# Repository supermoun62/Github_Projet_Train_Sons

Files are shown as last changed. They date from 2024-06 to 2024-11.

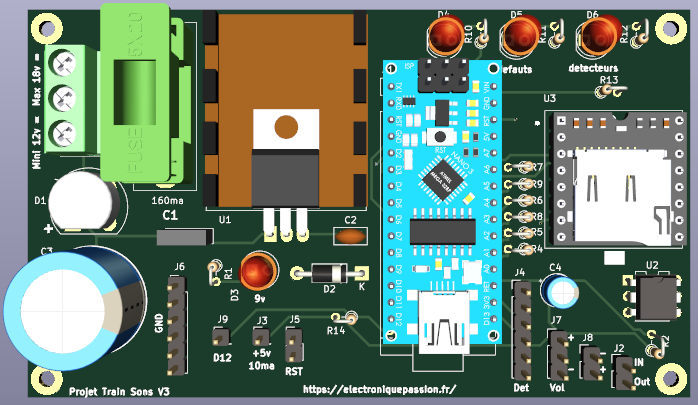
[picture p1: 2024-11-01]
PCB_Implantation_Projet_Trains_Sons.png

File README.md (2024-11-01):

Gestion de sons sur une maquette de trains.

Programmes Arduino:V1,V2,V3,V4,V5,V6

Materiel_Projet_Trains_Sons.pdf

Schema_Projet_Train_Sons.pdf
Schema_Nano.pdf

Documentations_Projet_Trains_Sons.pdf

Kicad_Gerber_Projet_Train_Sons

Kicad_PDF_Projet_Train_Sons

Le fichier Kicad_PDF_Projet_Train_Sons.pdf contient le détail du projet.

Schéma Projet_Trains_Sons: https://github.com/supermoun62/Github_Projet_Train_Sons/blob/main/Schema_Projet_Trains_Sons_V3.pdf

PCB Projet_Trains_Sons: https://github.com/supermoun62/Github_Projet_Train_Sons/blob/main/PCB_Implantation_Projet_Trains_Sons.png

Tracé Projet_Trains_Sons: https://github.com/supermoun62/Github_Projet_Train_Sons/blob/main/PCB_Projet_Trains_Sons_V3.png

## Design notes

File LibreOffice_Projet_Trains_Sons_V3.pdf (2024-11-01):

# PROJET

Commande de sons sur une maquette de trains.

Train-Sons | http://electroniquepassion.fr | 1 Sur 22

## Arduino - Trains - Sons

Le dossier comprend:

Programme Arduino.

Schéma de câblage.

Diverses documentations.

Liste du matériel.

Dossier Kicad en Gerber et PDF.

Train-Sons | http://electroniquepassion.fr | 2 Sur 22

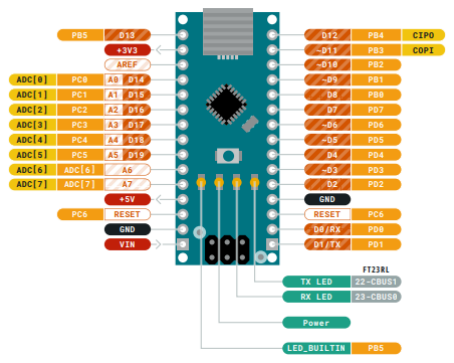
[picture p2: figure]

A4 = SDA
A5 = SCL

https://docs.arduino.cc/resources/pinouts/A000005-full-pinout.pdf

Train-Sons | http://electroniquepassion.fr | 3 Sur 22

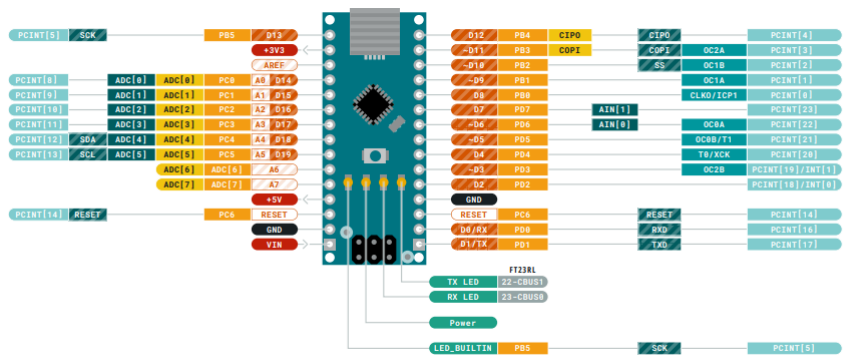
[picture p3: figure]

Train-Sons | http://electroniquepassion.fr | 4 Sur 22

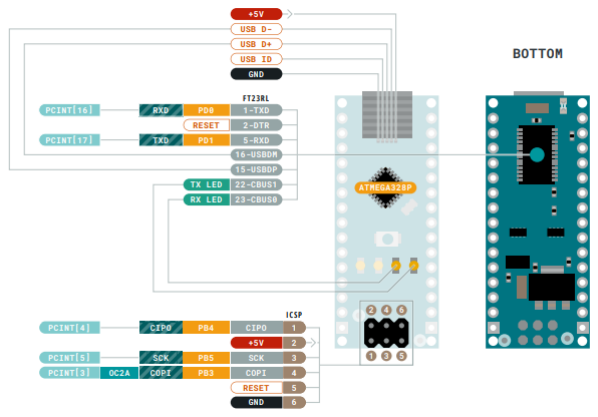
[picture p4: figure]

Train-Sons | http://electroniquepassion.fr | 5 Sur 22

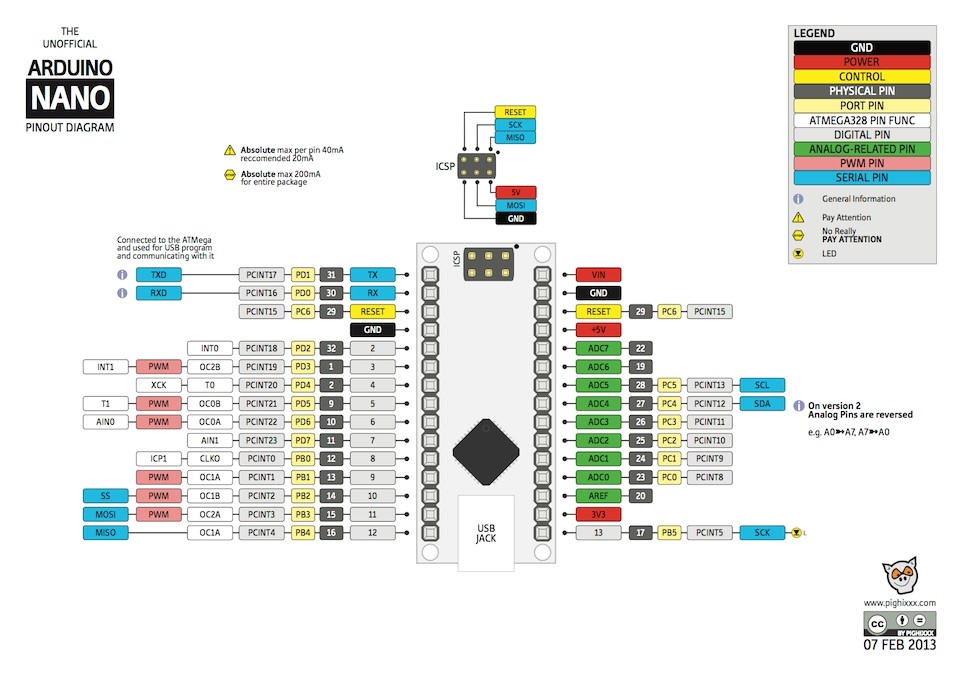
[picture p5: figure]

Train-Sons | http://electroniquepassion.fr | 6 Sur 22

https://docs.arduino.cc/learn/built-in-libraries/software-serial/ Traduction Google

La bibliothèque SoftwareSerial permet la communication série sur d’autres broches numériques d’une carte Arduino, en utilisant un logiciel pour répliquer la fonctionnalité (d’où le nom « SoftwareSerial »). Il est possible d’avoir plusieurs ports série logiciels avec des vitesses allant jusqu’à 115200 bps. Un paramètre active la signalisation inversée pour les appareils qui nécessitent ce protocole.

La version de SoftwareSerial incluse dans la version 1.0 et les versions ultérieures est basée sur la bibliothèque NewSoftSerial de 'Mikal Hart'.
Pour utiliser cette bibliothèque:
#include <SoftwareSerial.h>

Limites de cette bibliothèque
La bibliothèque SoftwareSerial présente les limitations connues suivantes :

Il ne peut pas transmettre et recevoir des données en même temps.
Si vous utilisez plusieurs ports série logiciels, un seul peut recevoir des données à la fois.
Toutes les broches des cartes Mega et Mega 2560 ne prennent pas en charge les interruptions de modification, de sorte que seules les broches suivantes peuvent être utilisées pour RX : 10, 11, 12, 13, 14, 15, 50, 51, 52, 53, A8 (62), A9 (63), A10 (64), A11 (65), A12 (66), A13 (67), A14 (68), A15 (69). Toutes les broches des cartes Leonardo et Micro ne prennent pas en charge les interruptions de changement, de sorte que seuls les éléments suivants peuvent être utilisés pour RX : 8, 9, 10, 11, 14 (MISO), 15 (SCK), 16 (MOSI).
Sur les cartes Arduino ou Genuino 101, la vitesse RX maximale actuelle est de 57600bps.
Sur les cartes Arduino ou Genuino 101, RX ne fonctionne pas sur la broche numérique 13. Methods
SoftwareSerial()
Créez une instance d’un objet SoftwareSerial. Plusieurs objets SoftwareSerial peuvent être créés, mais un seul peut être actif à un moment donné.
Syntax
SoftwareSerial(rxPin, txPin, inverse_logic)
Parameters
rxPin: the pin on which to receive serial data.
txPin: the pin on which to transmit serial data.
inverse_logic : utilisé pour inverser le sens des bits entrants (la valeur par défaut est la logique normale). S’il est défini, SoftwareSerial traite un LOW (0v sur la broche, normalement) sur la broche RX comme un bit de 1 (l’état d’inactivité) et un HIGH (5V sur la broche, normalement) comme un bit de 0. Cela affecte également la façon dont il écrit sur la broche TX. La valeur par défaut est false.
Returns

None.

Train-Sons | http://electroniquepassion.fr | 7 Sur 22

## Haut Parleur : Max 3W

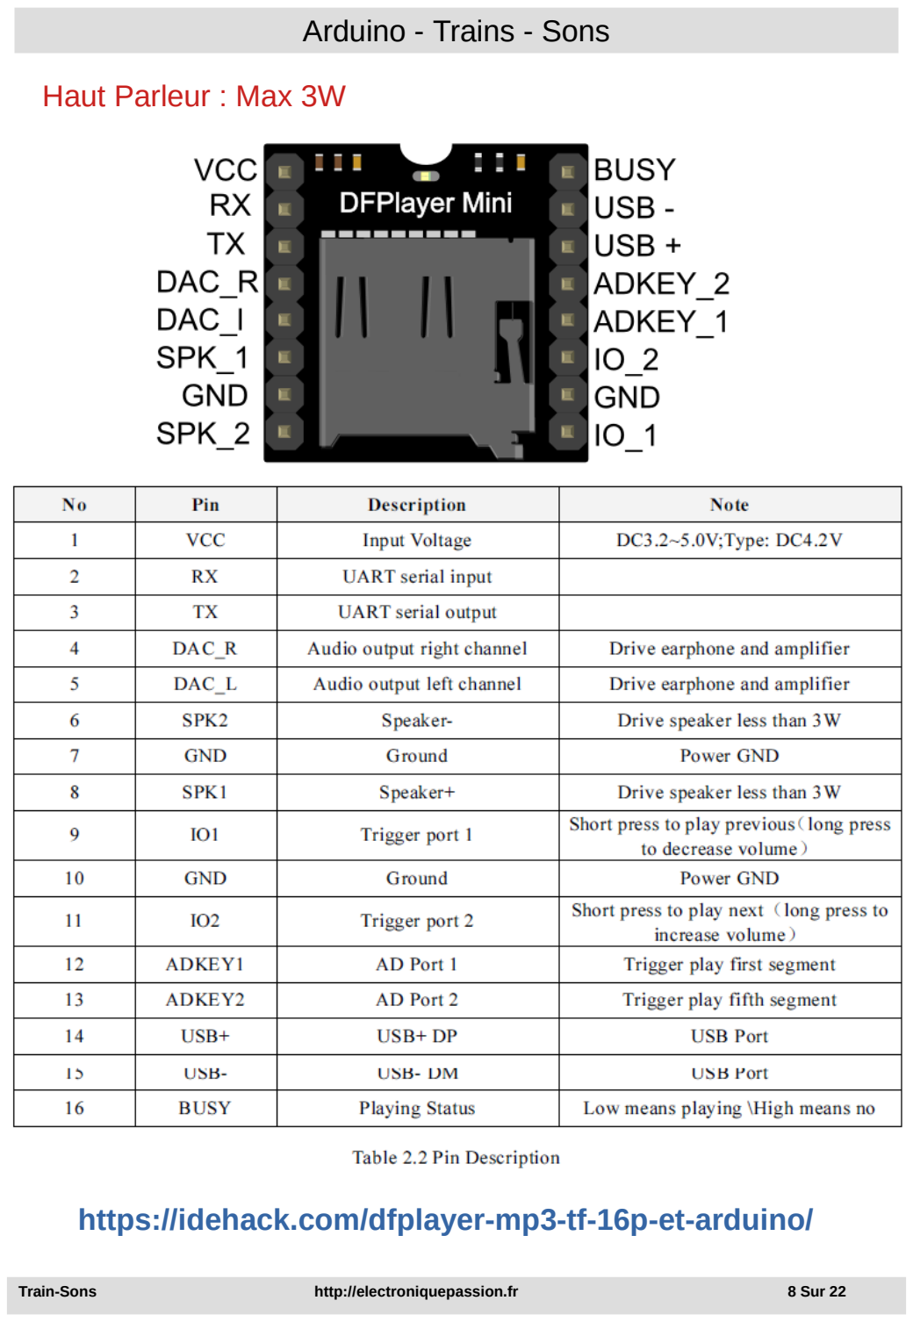
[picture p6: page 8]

https://wiki.dfrobot.com/DFPlayer_Mini_SKU_DFR0299

Train-Sons | http://electroniquepassion.fr | 8 Sur 22

## https://idehack.com/dfplayer-mp3-tf-16p-et-arduino/

Arduino_Train_Son_DFPlayer_Prog_Base.ino:

https://mytectutor.com/mp3-player-using-dfplayer-and-arduino/

https://github.com/DFRobot/DFPlayer-Mini-mp3?tab=readme-ov-file

https://github.com/DFRobot/DFRobot_utility

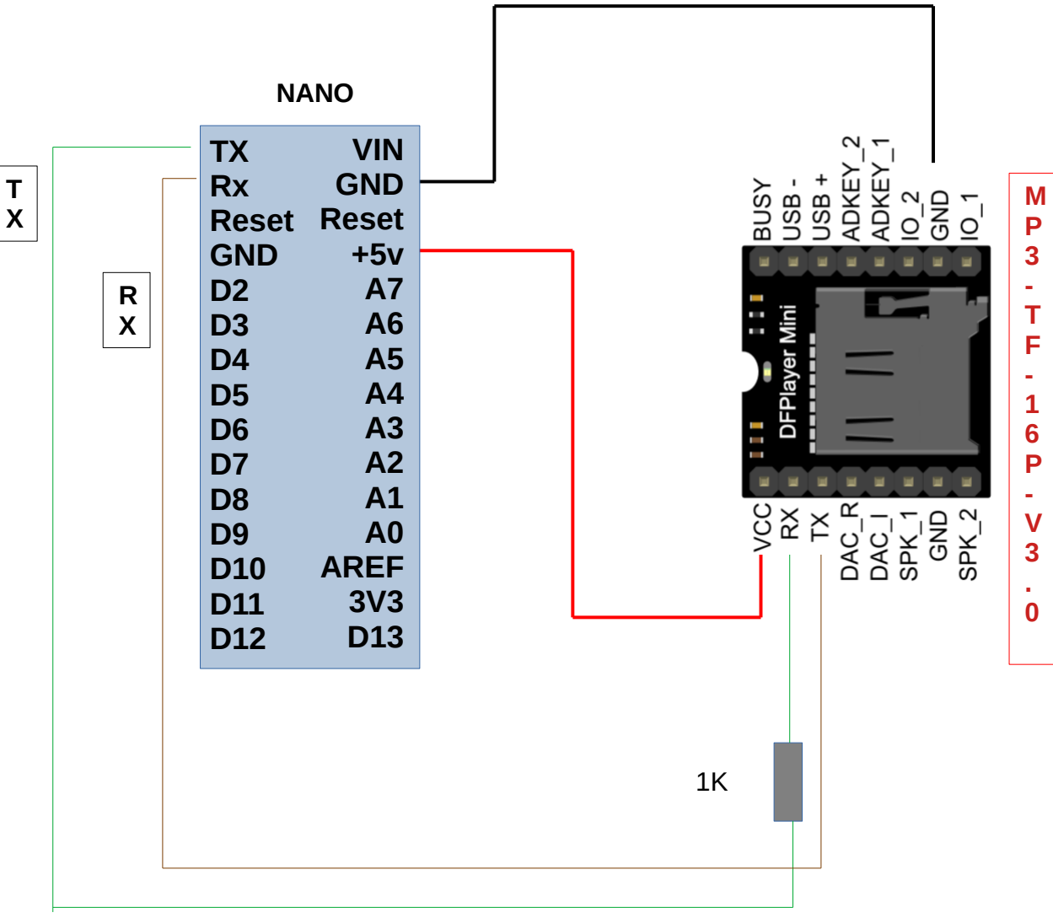
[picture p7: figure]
TX Rx Reset GND D2 D3 D4 D5 D6 D7 D8 D9 D10 D11 D12; NANO; VIN GND Reset +5v A7 A6 A5 A4 A3 A2 A1 A0 AREF 3V3 D13

En cas de transfert d’un programme, déconnecter les connexions TX et RX avant.

Train-Sons | http://electroniquepassion.fr | 9 Sur 22

Pour le programme de base :

Le contrôle simple du DFPlayer à l'aide d'Arduino, vous devrez installer la bibliothèque DFPlayer_Mini_Mp3.h et pour que cette bibliothèque fonctionne correctement, vous devrez également installer la bibliothèque DFRobot_utility.h.

Librairie DFRobotDFPlayerMini.h

https://github.com/DFRobot/DFRobotDFPlayerMini

Fonctions de base:

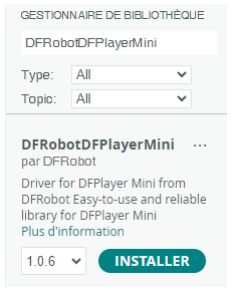
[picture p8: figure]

myDFPlayer.next(); | //Prochain fichier
myDFPlayer.previous(); | //Fichier précédent
myDFPlayer.play(1); | //Joue le premier fichier
myDFPlayer.loop(1); | //Joue le premier fichier en boucle
myDFPlayer.pause(); | //Mettre en pause la lecture
myDFPlayer.start(); | //reprendre la lecture du fichier en pause
myDFPlayer.playFolder(15, 4); //Joue le fichier 4 du dossier 15.
myDFPlayer.enableLoopAll(); | //Joue en boucle tous les fichiers.
myDFPlayer.disableLoopAll(); | //Arrête de lire en boucle tous les fichiers.
myDFPlayer.randomAll(); | //Joue tous les fichiers au hasard.
myDFPlayer.enableLoop(); | //Joue en boucle.
myDFPlayer.disableLoop(); | //Arrête la boucle.

Le nom du dossier allant de 1 à 99 et le nom du fichier de 1 à 255.

DFPlayer prend en charge les formats audio tels que MP3, WAV et WMA, qui peuvent être lus depuis une clé USB ou une carte SD.

REMARQUE: Le nom du dossier doit être mp3, placé sous le répertoire racine de la carte SD, et le nom du fichier mp3 doit être à 4 chiffres, par exemple, « 0001.mp3 », placé sous le dossier mp3. Si vous souhaitez le nommer à la fois en anglais et en chinois, vous pouvez l’ajouter après le numéro, par exemple, « 0001hello.mp3 » ou « 0001 后 » 来 .mp3".

Ou par le gestionnaire de
bibliothèque
Train-Sons | http://electroniquepassion.fr | 10 Sur 22

Arduino_Train_Son_DFPlayer_Prog_V1

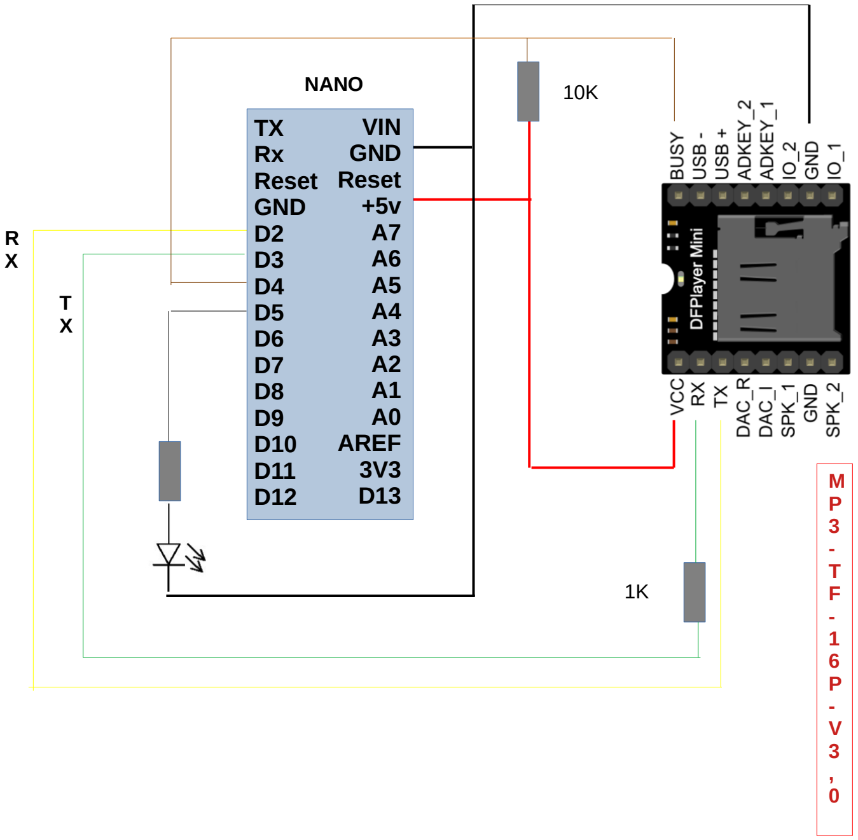
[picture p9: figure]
TX Rx Reset GND D2 D3 D4 D5 D6 D7 D8 D9 D10 D11 D12; NANO; VIN GND Reset +5v A7 A6 A5 A4 A3 A2 A1 A0 AREF 3V3 D13

Train-Sons | http://electroniquepassion.fr | 11 Sur 22

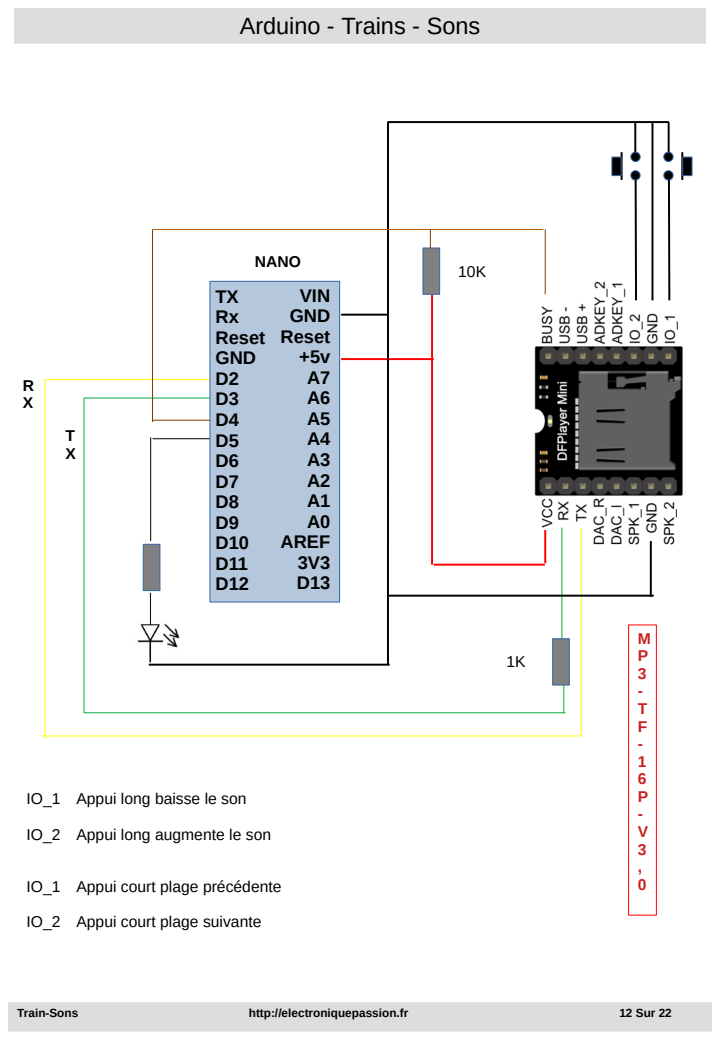
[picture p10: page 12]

IO_1 Appui long baisse le son

IO_2 Appui long augmente le son

IO_1 Appui court plage précédente

IO_2 Appui court plage suivante

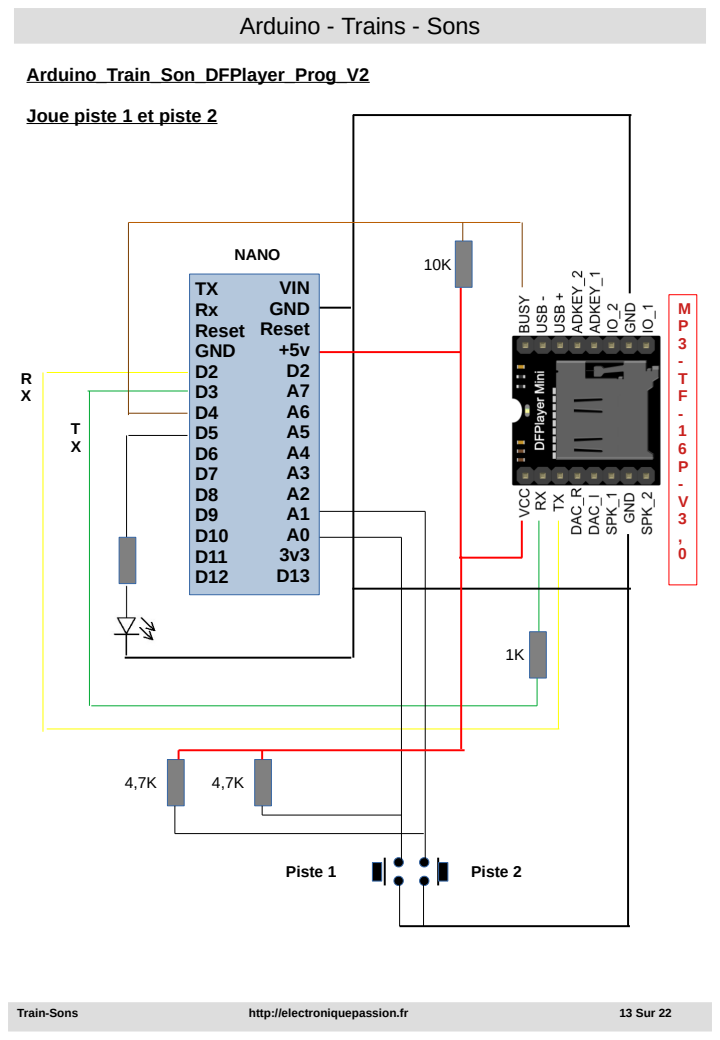
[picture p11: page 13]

Joue piste 1 et piste 2

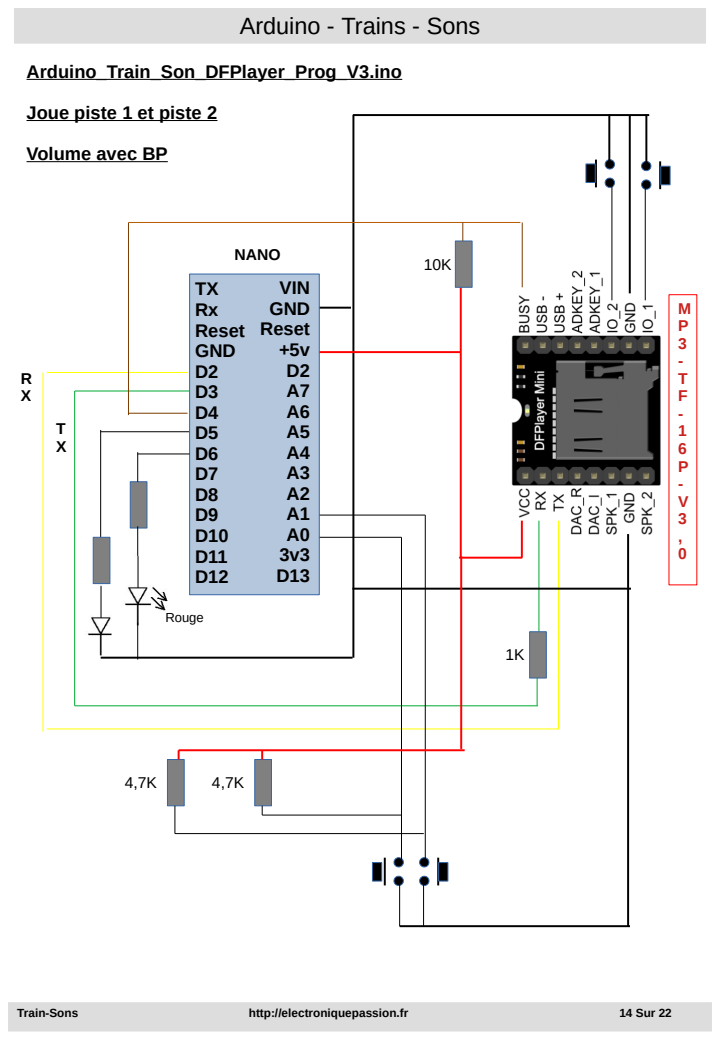
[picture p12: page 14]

Joue piste 1 et piste 2

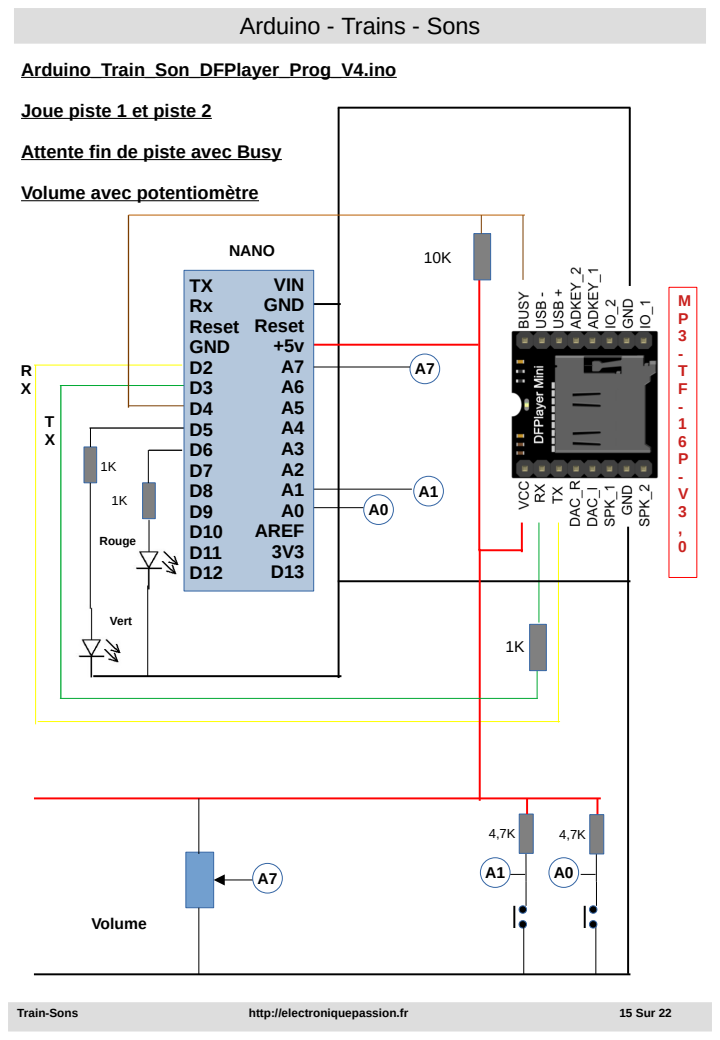
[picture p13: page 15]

Joue piste 1 et piste 2

Attente fin de piste avec Busy

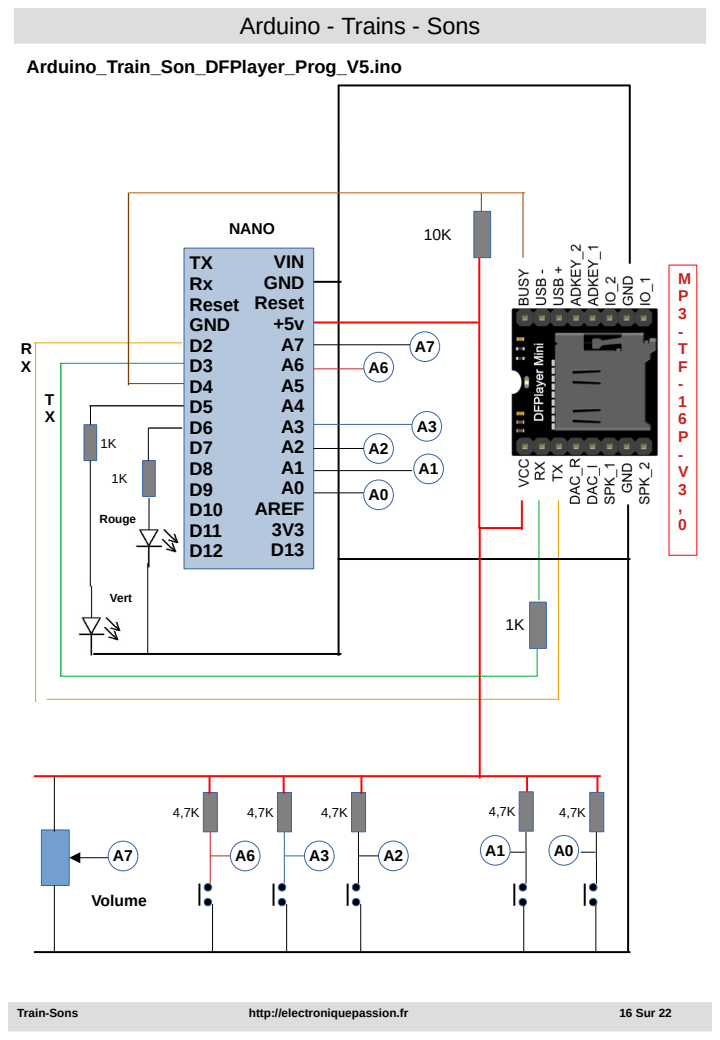
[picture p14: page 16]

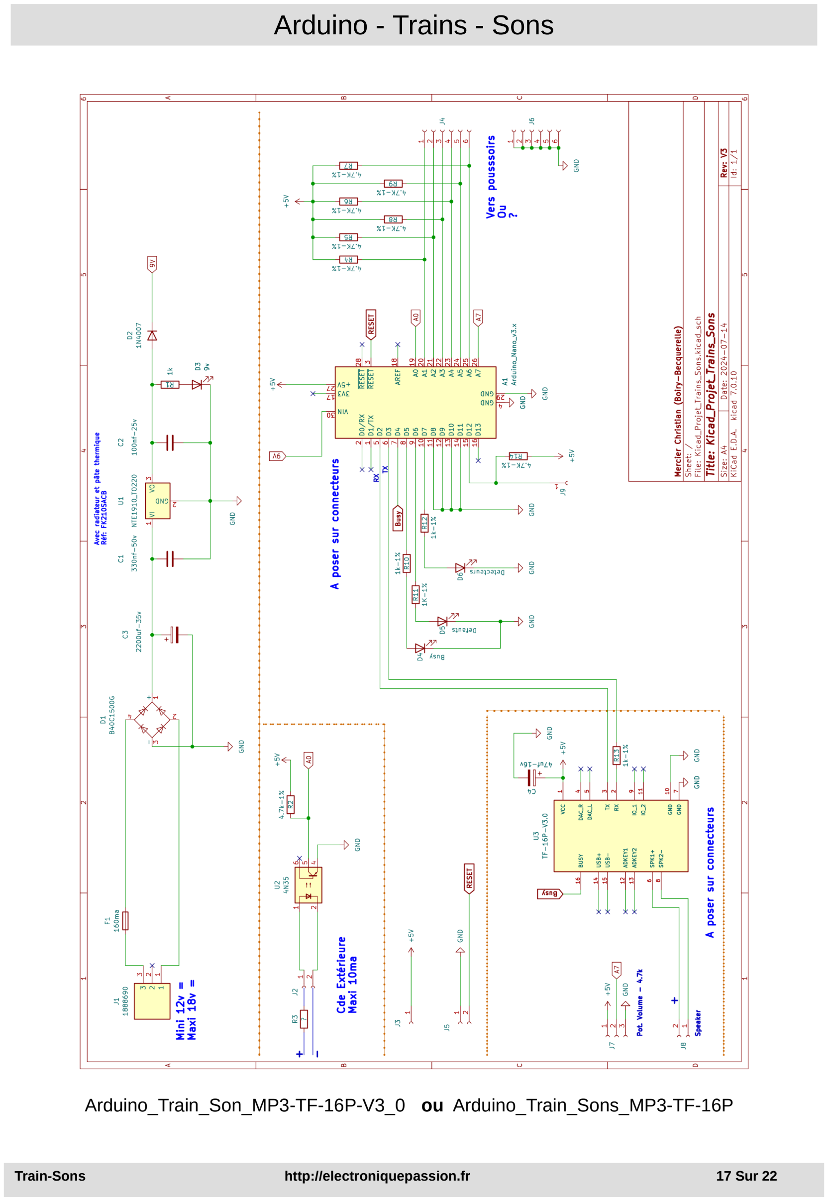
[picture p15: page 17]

Train-Sons | http://electroniquepassion.fr | 17 Sur 22

Arduino_Train_Son_MP3-TF-16P-V3_0 ou Arduino_Train_Sons_MP3-TF-16P

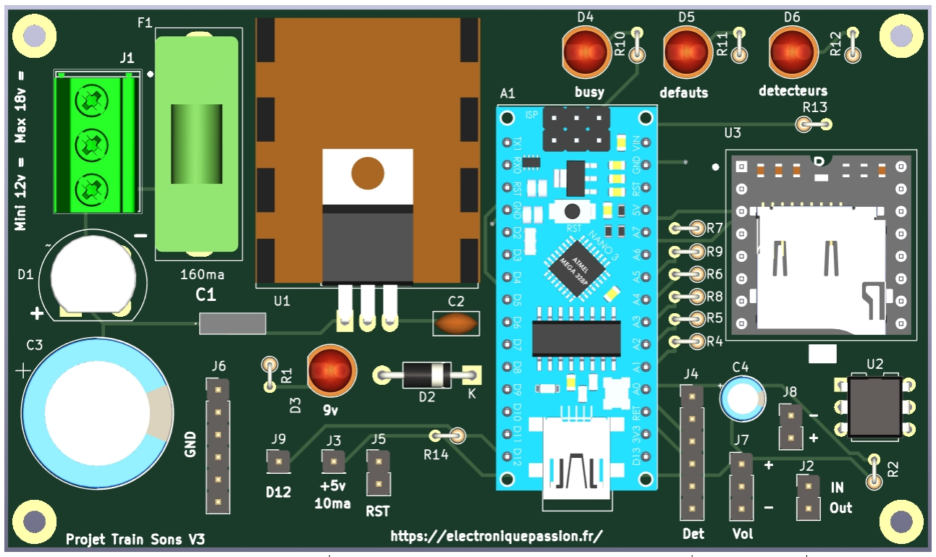
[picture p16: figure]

Train-Sons | http://electroniquepassion.fr | 18 Sur 22

0n peut relier J2 au connecteur J6 du projet Passage_A_niveau_Stockage_V4. Information sur le site:https://electroniquepassion.fr

Ne pas oublier la résistance R3 (voir image suivante)

GND

+5v
Maxi 10ma

Reset
Haut
parleur

Commande extérieure
avec isolation de potentiel. Courant à limiter à 10ma avec résistance(R3,sur le plan) Impulsion de 100ms

Entrée,Sortie
D12

Commandes

Train-Sons | http://electroniquepassion.fr | 19 Sur 22

Carte SD

## Les essais ont été effectués avec une carte formatée en

Fat 32.

Dossier intitulé mp3 à la racine.

## Fichiers sons nommés en 0001.mp3 0002.mp3 ------------- -------------

Carte passage à
niveau en stockage

Carte sons

+ 5v | D11 | OUT | IN

1k

J6 | J2

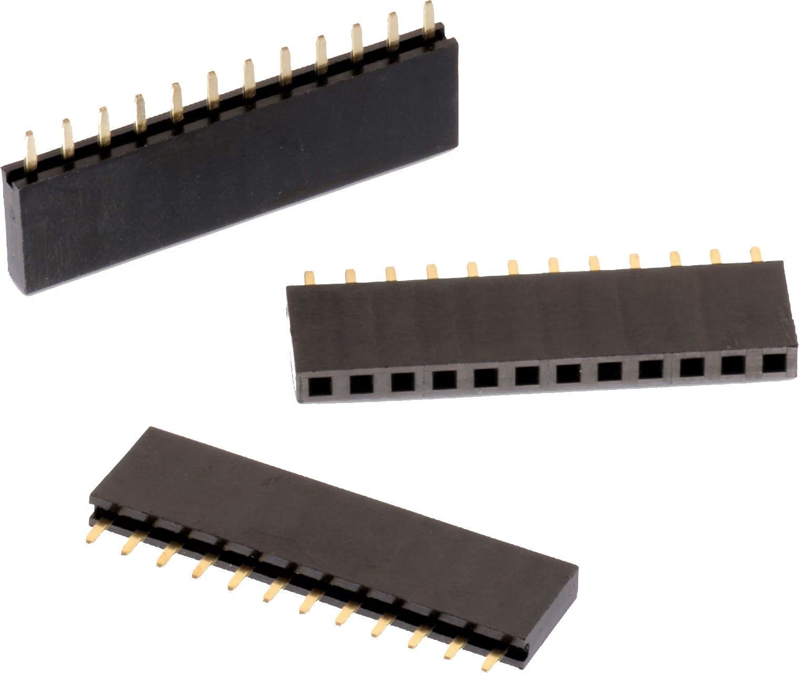
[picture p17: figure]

Train-Sons | http://electroniquepassion.fr | 20 Sur 22

https://www.we-online.com/en/components/products/PHD_2_54_SOCKET_HEADER_6130 XX11821 (https://www.we-online.com/en/components/products/PHD_2_54_SOCKET_HEADER_6130XX11821)

Train-Sons | http://electroniquepassion.fr | 21 Sur 22

Liens:

https://lasonotheque.org/search?q=train

https://idehack.com/dfplayer-mp3-tf-16p-et-arduino/

https://www.electronics-lab.com/project/mp3-player-using-arduino-dfplayer-mini/

https://www.wikidebrouillard.org/wiki/Item:DFPlayer_Lecteur_MP3

https://wiki.dfrobot.com/DFPlayer_Mini_SKU_DFR0299#Connection_Diagram

https://wiki.dfrobot.com/DFPlayer_Mini_SKU_DFR0299

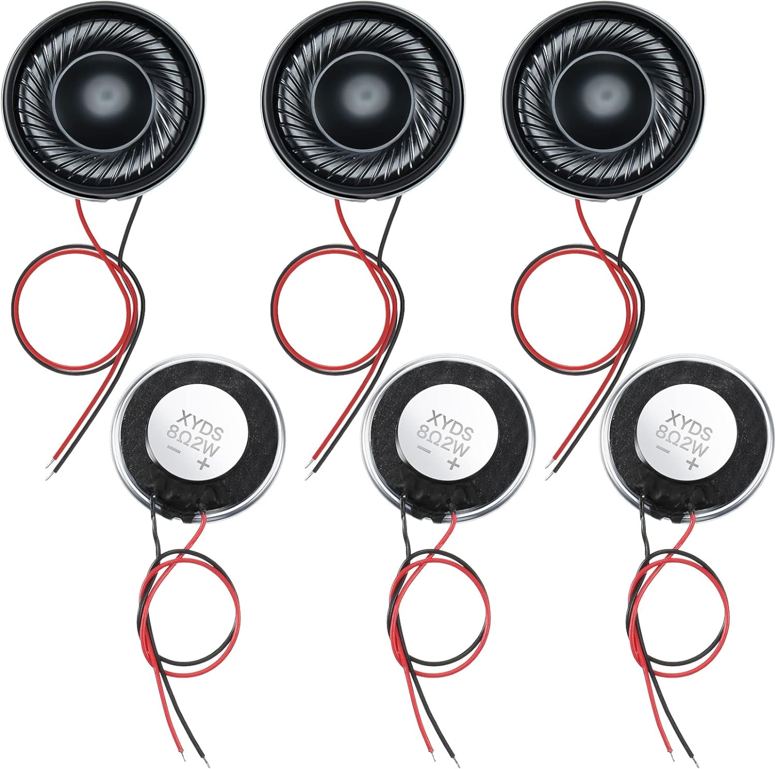
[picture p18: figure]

Weewooday Petits Haut-Parleurs 2 W 8 ohms Haut-Parleur à Aimant Interne Rond à Coque Métallique Micro Haut-Parleur Interne pour Mini Haut-Parleurs, DVD, EVD, Mini Haut-Parleurs Multimédia

Train-Sons | http://electroniquepassion.fr | 22 Sur 22

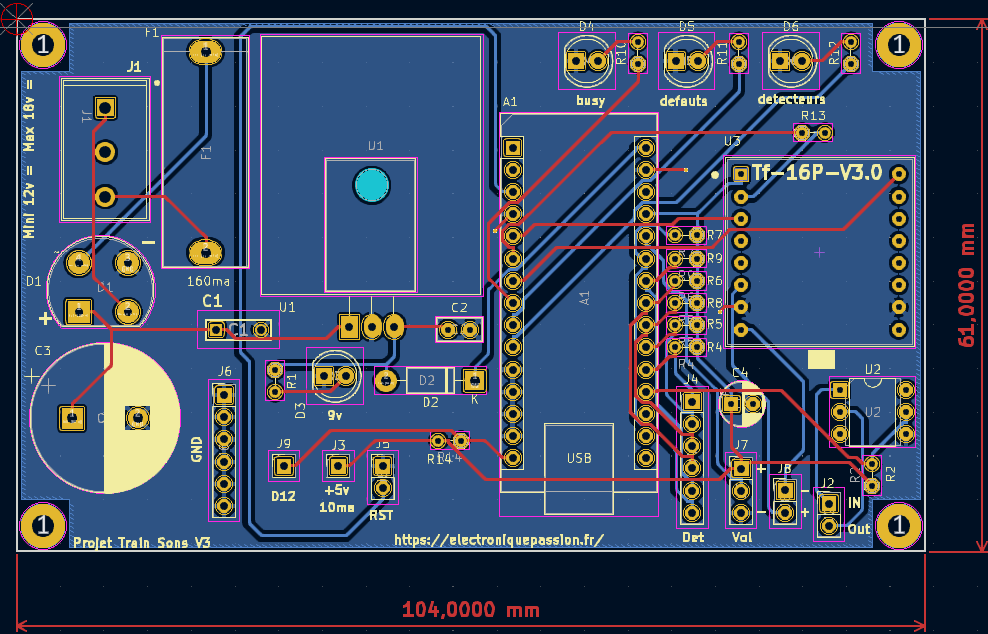
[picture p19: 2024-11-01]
PCB_Projet_Trains_Sons_V3.png

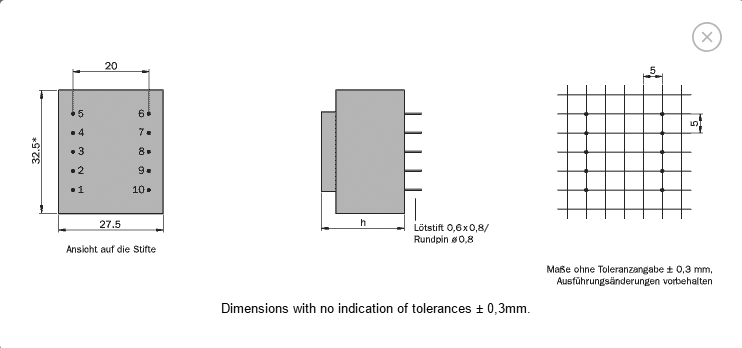
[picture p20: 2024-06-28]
Documentations_Projet_Trains_Sons/BVEI3052052_Dimensions.png

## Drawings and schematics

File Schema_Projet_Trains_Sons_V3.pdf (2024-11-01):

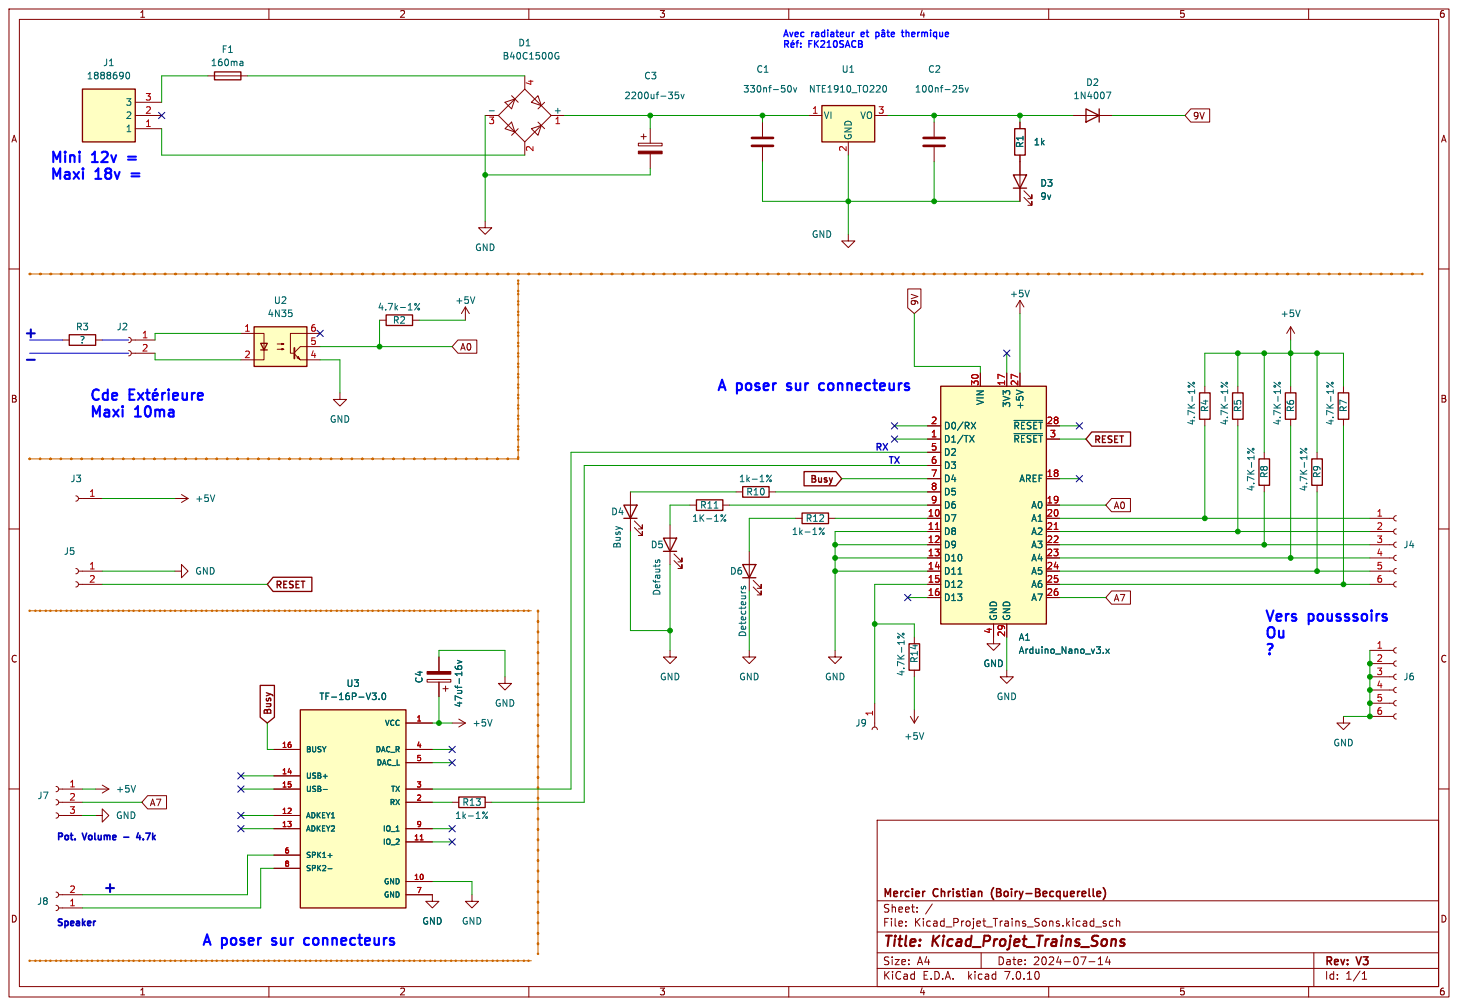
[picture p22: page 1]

Avec radiateur et þÿpâtehermique
þÿRéf: FK210SACB

TX RX Cde þÿExtérieure
Maxi 10ma

File: Kicad_Projet_Trains_Sons.kicad_sch Sheet: / Mercier Christian (Boiry-Becquerelle)

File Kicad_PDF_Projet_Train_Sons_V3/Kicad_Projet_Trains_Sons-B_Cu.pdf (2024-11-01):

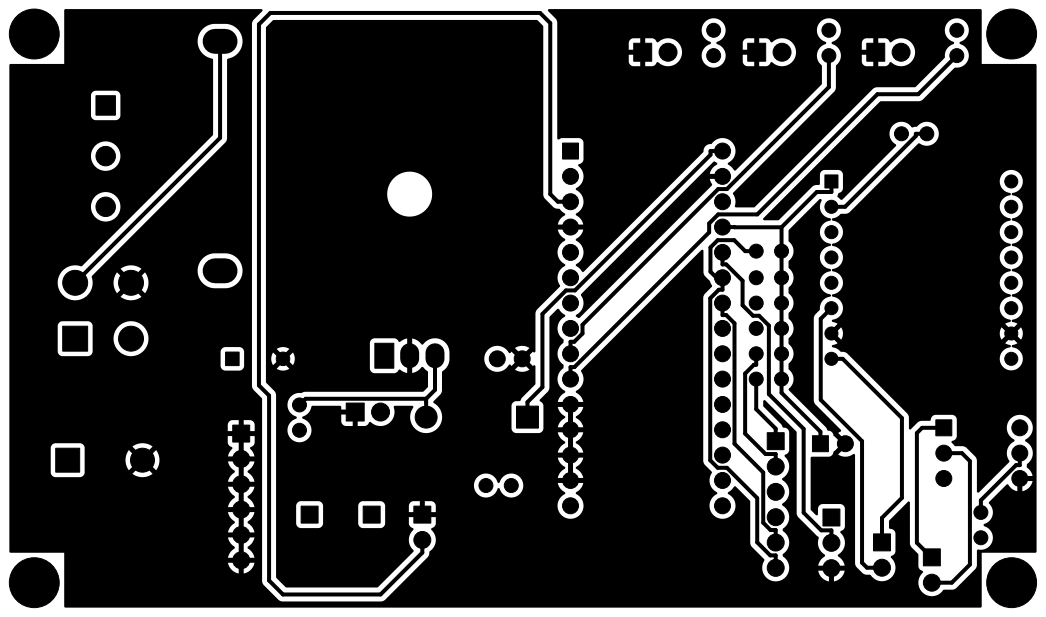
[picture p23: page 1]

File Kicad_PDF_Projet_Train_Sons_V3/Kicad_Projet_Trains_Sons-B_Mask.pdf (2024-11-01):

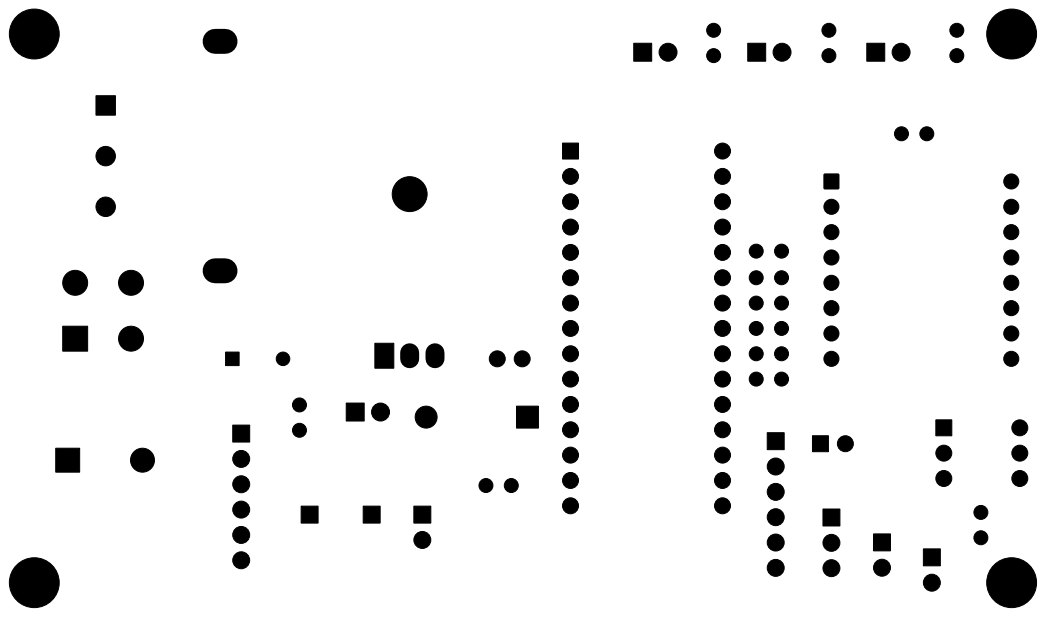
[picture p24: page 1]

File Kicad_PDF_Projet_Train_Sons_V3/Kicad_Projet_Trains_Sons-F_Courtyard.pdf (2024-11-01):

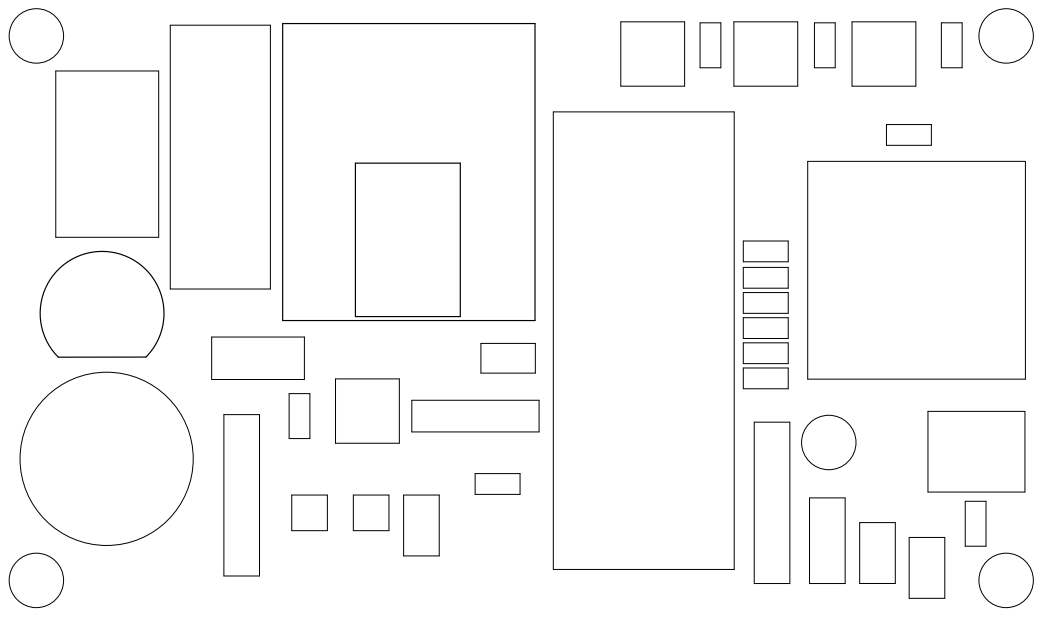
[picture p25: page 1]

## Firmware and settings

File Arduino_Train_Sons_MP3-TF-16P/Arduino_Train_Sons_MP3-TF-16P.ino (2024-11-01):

/***************************************************************************************************
Synopsis:   Commande sons avec carte MP3-TF-16P
Carte:      Arduino Nano
Capteur:    Capteurs ILS  
             
Biblio:     SoftwareSerial.h
            DFPlayer.h
             
Source:               https://github.com/enjoyneering/DFPlayer

                      ESP8266 Core     -https://github.com/esp8266/Arduino
                      EspSoftwareSerial-https://github.com/plerup/espsoftwareserial

Librairie DFPlayer.h  https://github.com/enjoyneering/DFPlayer 

Informations sites:    https://lasonotheque.org/dossier-62-fabriquer-boite-sons-arduino-dfplayer.html

                       https://docs.arduino.cc/learn/built-in-libraries/software-serial/

                       https://idehack.com/dfplayer-mp3-tf-16p-et-arduino/
                        
                       https://lasonotheque.org/fabriquer-boite-sons-arduino-dfplayer_f62.html

                       https://wiki.dfrobot.com/DFPlayer_Mini_SKU_DFR0299#Connection_Diagram

                       https://wiki.dfrobot.com/DFPlayer_Mini_SKU_DFR0299

                       https://www.wikidebrouillard.org/wiki/Item:DFPlayer_Lecteur_MP3
          
Pssibilté de piloter un son avec la carte Projet_Passage_A_niveau_Stockage           
Auteur:  Christian Mercier  
  Créé le: 11/08/2024 
  62128 Boiry-Becquerelle France           
  https://electroniquepassion.fr/ 
  C.Mercier  62128 Boiry-Becquerelle  

***************************************************************************************************
   This is an Arduino sketch for DFPlayer Mini MP3 module
   written by : enjoyneering
   source code: https://github.com/enjoyneering/DFPlayer

   DFPlayer Mini features:
   - 3.2v..5.0v, typical 4.2v
   - 15mA without flash drive, typical 24mA
   - 24-bit DAC with 90dB output dynamic range and SNR over 85dB
   - micro SD-card, up to 32GB (FAT16, FAT32)
   - USB-Disk up to 32GB (FAT16, FAT32)
   - supports mp3 sampling rate 8KHz, 11.025KHz, 12KHz, 16KHz, 22.05KHz, 24KHz, 32KHz, 44.1KHz, 48KHz
   - supports up to 100 folders, each folder can be assigned to 001..255 songs
   - built-in 3W mono amplifier, NS8002 AB-Class with standby function
   - UART to communicate, 9600bps (parity:none, data bits:8, stop bits:1, flow control:none)

   NOTE:
   - if you hear a loud noise, add a 1K resistor in series with DFPlayer TX pin
   - move the jumper from right to left to automatically switch the amplifier to standby

   Frameworks & Libraries:
   ESP8266 Core      -  https://github.com/esp8266/Arduino
   EspSoftwareSerial -  https://github.com/plerup/espsoftwareserial


   GNU GPL license, all text above must be included in any redistribution,
   see link for details  - https://www.gnu.org/licenses/licenses.html

   Librairie DFPlayer.h  https://github.com/enjoyneering/DFPlayer  
***************************************************************************************************
    NOTE:
    - moduleType:
      - DFPLAYER_MINI:
        - DFPlayer Mini module
        - MP3-TF-16P module
        - FN-M16P module
        - YX5200 chip
        - YX5300 chip
        - JL AAxxxx chip
      - DFPLAYER_FN_X10P:
        - FN-M10P module
        - FN-S10P module
        - FN6100 chip
      - DFPLAYER_HW_247A:
        - HW-247A module
        - GD3200B chip
      - DFPLAYER_NO_CHECKSUM:
        - no checksum calculation (not recomended for MCU without external
          crystal oscillator)
    MOTS CLES:
        https://github.com/enjoyneering/DFPlayer/blob/main/keywords.txt
***************************************************************************************************/
#include <SoftwareSerial.h>
#include <DFPlayer.h>
#define MP3_RX_PIN                    2     //GPIO4/D2 to DFPlayer Mini TX
#define MP3_TX_PIN                    3     //GPIO5/D1 to DFPlayer Mini RX
#define myDFPlayer_SERIAL_SPEED       9600  //DFPlayer Mini suport only 9600-baud
#define myDFPlayer_SERIAL_BUFFER_SIZE 32    /*software serial buffer size in bytes, to send 8-bytes you need
                                            11-bytes buffer (start byte+8-data bytes+parity-byte+stop-byte=11-bytes)*/
#define myDFPlayer_SERIAL_TIMEOUT     350   //average DFPlayer response timeout for GD3200B chip 350msec..500msec
SoftwareSerial myDFPlayerSerial(MP3_RX_PIN,MP3_TX_PIN);//RX, TX
DFPlayer myDFPlayer;

  const int SON_1 = 1;
  const int SON_2 = 2;
  const int SON_3 = 3;
  const int SON_4 = 4;
  const int SON_5 = 5;
  const int SON_6 = 6;
  const int SON_7 = 7;
  const int SON_8 = 8;
  const int SON_9 = 9;
  const int SON_10 = 10;
  const int SON_11 = 11;
  const int SON_12 = 12;
  const int SON_13 = 13;
  const int SON_14 = 14;
  const int SON_15 = 15;
  const int SON_16 = 16;
  const int SON_17 = 17;
  const int SON_18 = 18;
  const int SON_19 = 19;
  const int SON_20 = 20;

  int etatA0 = 0;
  int etatA1 = 0;
  int etatA2 = 0;
  int etatA3 = 0;
  int etatA4 = 0;
  int etatA5 = 0;
  int etatA6 = 0;
  int etatA7= 0;
  int valVolume = 0; 
  const byte BUSY = 4;// Information TF-16P-V3
  byte etatBusy = 0;
  bool memoireEntreA1 = 0;

  const byte LED5 = 5;//Busy
  const byte LED6 = 6;//defaut
  const byte LED7 = 7;//Entrees
  const byte LED13 = 13;// Info reset TF-16P-V3

  unsigned long tempsPrecedentReset = 0;
  unsigned long tempsPrecedentSon1 = millis();
  unsigned long tempsPrecedentSon2 = 0;

  bool bitSon1 = 1;
  bool bitSon2 = 0;
  unsigned long compteur1 = 0;
  unsigned long compteur2 = 0;

  unsigned long tempsCourant = 0;
//------------------------------------------
void setup()
{
  Serial.begin(115200);  
  myDFPlayerSerial.begin(9600);
  myDFPlayer.begin(myDFPlayerSerial, myDFPlayer_SERIAL_TIMEOUT, DFPLAYER_HW_247A, false);
                                                 //"DFPLAYER_HW_247A" see NOTE, false=no feedback from module after the command
  myDFPlayer.stop();                             //if player was runing during ESP8266 reboot
  myDFPlayer.reset();                            //reset all setting to default
  myDFPlayer.setSource(2);                       //1=USB-Disk, 2=TF-Card, 3=Aux, 4=Sleep, 5=NOR Flash
  myDFPlayer.setEQ(0);                           //0=Off, 1=Pop, 2=Rock, 3=Jazz, 4=Classic, 5=Bass
  myDFPlayer.setVolume(25);                      //0..30, module persists volume on power failure
  myDFPlayer.sleep();                            //inter sleep mode, 24mA
  myDFPlayer.wakeup(2);                          //exit sleep mode & initialize source 1=USB-Disk, 2=TF-Card, 3=Aux, 5=NOR Flash 
  Serial.println(myDFPlayer.getStatus());        //0=stop, 1=playing, 2=pause, 3=sleep or standby, 4=communication error, 5=unknown state
  Serial.println(myDFPlayer.getVolume());        //0..30
  Serial.println(myDFPlayer.getCommandStatus()); //1=module busy, 2=module sleep, 3=request not fully received, 4=checksum not match
                                                 //5=requested folder/track out of range, 6=requested folder/track not found
                                                 //7=advert available while track is playing, 8=SD card not found, 9=???, 10=module sleep
                                                 //11=OK command accepted, 12=OK playback completed, 13=OK module ready after reboot 
  pinMode(LED5, OUTPUT); 
  pinMode(LED6, OUTPUT); 
  pinMode(LED7, OUTPUT);
  pinMode(LED13, OUTPUT);     

  myDFPlayer.playTrack(SON_14);  
}//FIN SETUP  
//------------------------------------------
void loop()
{
  etatA0 = analogRead(A0);
  etatA1 = analogRead(A1);
  etatA2 = analogRead(A2);
  etatA3 = analogRead(A3);
  etatA4 = analogRead(A4);
  etatA5 = analogRead(A5);
  etatA6 = analogRead(A6);
  etatA7= analogRead(A7);// potentiometre volume
  etatBusy = digitalRead(BUSY);    
  valVolume = map(analogRead(A7),0,1023,0,30); 
/******************************
  Commandes sons avec Entrees
*******************************/
  if(etatA0 <=512 && etatBusy == 1)
    {
        myDFPlayer.setTimeout(350);
        delay(40);
        myDFPlayer.setVolume(valVolume);        
        myDFPlayer.playTrack(SON_9);        
    }
  if(etatA1 <=512 && etatBusy == 1)
    {        
        myDFPlayer.setTimeout(350);
        delay(40);
        myDFPlayer.setVolume(valVolume);
        myDFPlayer.playTrack(SON_1);        
    }
  if(etatA2 <=512 && etatBusy == 1)
    {
        myDFPlayer.setTimeout(350);
        delay(40);
        myDFPlayer.setVolume(valVolume);        
        myDFPlayer.playTrack(SON_2);        
    }
  if(etatA3 <=512 && etatBusy == 1)
    {
        myDFPlayer.setTimeout(350);
        delay(40);
        myDFPlayer.setVolume(valVolume);        
        myDFPlayer.playTrack(SON_3);        
    }
  if(etatA4 <=512 && etatBusy == 1)
    {
        myDFPlayer.setTimeout(350);
        delay(40);
        myDFPlayer.setVolume(valVolume);       
        myDFPlayer.playTrack(SON_4);       
    }
  if(etatA5 <=512 && etatBusy == 1)
    {
        myDFPlayer.setTimeout(350);
        delay(40);
        myDFPlayer.setVolume(valVolume);        
        myDFPlayer.playTrack(SON_5);        
    }
  if(etatA6 <=512 && etatBusy == 1)
    {
        myDFPlayer.setTimeout(350);
        delay(40);
        myDFPlayer.setVolume(valVolume);        
        myDFPlayer.playTrack(SON_6);        
    }
/******************************
  Commandes sons avec interval
*******************************/
    if((millis() - tempsPrecedentSon1) >= 480000 && (bitSon1 == 1))//8 minutes (en ms)
      {
        tempsPrecedentSon1 = millis(); 
        tempsPrecedentSon2 = millis();       
        bitSon1 = 0;
        bitSon2 = 1; 
        compteur1 = compteur1 + 1;
        myDFPlayer.setTimeout(500);
        delay(40);
        myDFPlayer.setVolume(valVolume);
        myDFPlayer.playTrack(SON_12);
      }
    if((millis() - tempsPrecedentSon2) >= 120000 && (bitSon2 == 1))//2 minutes (en ms)
      {
        tempsPrecedentSon2 = millis();
        tempsPrecedentSon1 = millis();        
        bitSon1 = 1;
        bitSon2 = 0; 
        compteur2 = compteur2 + 1;
        myDFPlayer.setTimeout(500);
        delay(40);
        myDFPlayer.setVolume(valVolume);
        myDFPlayer.playTrack(SON_13);
      }        
Signalisations();// Appel Signalisation
/******************************
         Reset TF-16P
*******************************/
    if(etatBusy == 1)
      {
        tempsPrecedentReset = millis();
      }
    if(etatBusy == 0)
      {
        if((millis() - tempsPrecedentReset) >= 130000 )// 130 secondes en ms
          {
            tempsPrecedentReset = millis();
            myDFPlayer.reset();
            digitalWrite(LED13, HIGH);
            delay(1000);
            digitalWrite(LED13, LOW);
          }
      }  
    Serial.print("A0:");
    Serial.print(etatA0);
    Serial.print("\t");
    Serial.print("A1:");    
    Serial.print(etatA1);
    Serial.print("\t");
    Serial.print("A2:");
    Serial.print(etatA2);
    Serial.print("\t");
    Serial.print("A3:");
    Serial.print(etatA3);
    Serial.print("\t");
    Serial.print("A4:");
    Serial.print(etatA4);
    Serial.print("\t");
    Serial.print("A5:");
    Serial.print(etatA5);
    Serial.print("\t");
    Serial.print("A6:");
    Serial.print(etatA6);
    Serial.print("\t");
    Serial.print("Potar: ");    
    Serial.print(etatA7);
    Serial.print("\t");
    Serial.print("Busy: ");
    Serial.print(etatBusy);
    Serial.print("\t");
    Serial.print("bitSon1: ");  
    Serial.print(bitSon1);
    Serial.print("\t");
    Serial.print("bitSon2: ");   
    Serial.print(bitSon2);
    Serial.print("\t");
    Serial.print("C1: ");   
    Serial.print(compteur1);    
    Serial.print("\t");
    Serial.print("C2: ");    
    Serial.println(compteur2);
}//FIN LOOP
//------------------------------------------
void Signalisations()
  {
    if (etatA0 < 512 || etatA1 < 512 || etatA2 < 512 || etatA3 < 512 || etatA4 < 512 || etatA5 < 512 || etatA6 < 512)
      {
        digitalWrite(LED7, HIGH);
      }      
    else
      {
        digitalWrite(LED7, LOW);
      }

    if(etatBusy == 0) 
      {
        digitalWrite(LED5, HIGH);
      } 
    else
      {
        digitalWrite(LED5, LOW);
      }
  }// FIN FONCTION SIGNALISATION 

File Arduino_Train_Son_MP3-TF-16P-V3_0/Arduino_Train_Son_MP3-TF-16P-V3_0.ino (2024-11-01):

/* Description: Programme V10 permettant la diffusion d'un son avec un DFPlayerMini 
  Carte   : Arduino Nano
  DFPlayerMini (Mp3 TF 16P V3.0)

 Librairies utilisées:  DFRobotDFPlayerMini.h 
                        https://github.com/DFRobot/DFRobotDFPlayerMini 
                        SoftwareSerial.h
                        https://docs.arduino.cc/learn/built-in-libraries/software-serial/
                     
 Informations sites:    https://lasonotheque.org/dossier-62-fabriquer-boite-sons-arduino-dfplayer.html

                        https://docs.arduino.cc/learn/built-in-libraries/software-serial/

                        https://idehack.com/dfplayer-mp3-tf-16p-et-arduino/
                        
                        https://lasonotheque.org/fabriquer-boite-sons-arduino-dfplayer_f62.html

                        https://wiki.dfrobot.com/DFPlayer_Mini_SKU_DFR0299#Connection_Diagram

                        https://wiki.dfrobot.com/DFPlayer_Mini_SKU_DFR0299

                        https://www.wikidebrouillard.org/wiki/Item:DFPlayer_Lecteur_MP3
  
  Auteur:  Christian Mercier  
  Créé le: 11/08/2024 
  62128 Boiry-Becquerelle France                                        
*/
#include <SoftwareSerial.h>
#include <DFRobotDFPlayerMini.h>
// Set up a new SoftwareSerial object
SoftwareSerial mySoftwareSerial (2,3);//rxPin, txPin
//*****************************************************
// Create the Player object
DFRobotDFPlayerMini myDFPlayer;
//*****************************************************
const int E0 = 0;
int etatE0 = 0;
const int E1 = 1;
int etatE1 = 0;
const int E2 = 2;
int etatE2 = 0;
const int E3 = 3;
int etatE3 = 0;
const int E4 = 4;
int etatE4 = 0;
const int E5 = 5;
int etatE5 = 0;
const int E6 = 6;
int etatE6 = 0;
const int E7 = 7;
int etatE7 = 0;
int valVolume = 0;
const byte BUSY = 4;// Information TF-16P-V3
byte etatBusy = 0;

const byte LED5 = 5;//Busy
const byte LED6 = 6;//defaut
const byte LED7 = 7;//Entrees
const byte LED13 = 13;// Info reset TF-16P-V3

unsigned long tempsPrecedentReset = 0;
unsigned long tempsPrecedentSon1 = millis();
unsigned long tempsPrecedentSon2 = 0;

bool bitSon1 = 1;
bool bitSon2 = 0;
unsigned long compteur1 = 0;
unsigned long compteur2 = 0;
//------------------------------------------
void setup()
  {
    Serial.begin(115200);
    delay(500);
//*****************************************************
    // Define pin modes for TX and RX
    //pinMode(rxPin, INPUT);
    //pinMode(txPin, OUTPUT);
    // Set the baud rate for the SoftwareSerial object
    mySoftwareSerial.begin(9600);
    myDFPlayer.begin(mySoftwareSerial) ;
    delay(500);
//*****************************************************
    pinMode(LED5, OUTPUT); 
    pinMode(LED6, OUTPUT); 
    pinMode(LED7, OUTPUT);
    pinMode(LED13, OUTPUT);
//*****************************************************
   if (!myDFPlayer.begin(mySoftwareSerial)) //Utilisation de  softwareSerial pour communiquer
    {  
      Serial.println(F("Pb communication:"));
      Serial.println(F("1.SVP verifier connexion serie!"));
      Serial.println(F("2.SVP verifier SDcard !"));
      while(true)
        {
          digitalWrite(LED6, HIGH);  
        }
    }
    Serial.println(F("DFPlayer Mini En ligne."));

//*****************************************************    
    myDFPlayer.setTimeOut(500) ;
    delay(40);
    myDFPlayer.volume(20);// Volume à la mise sous tension  
    myDFPlayer.play(7);// Son à la mise sous tension       
  }//FIN SETUP  
//------------------------------------------
void loop()
  {
    etatE0 = analogRead(E0);
    etatE1 = analogRead(E1);
    etatE2 = analogRead(E2);
    etatE3 = analogRead(E3);
    etatE4 = analogRead(E4);
    etatE5 = analogRead(E5);
    etatE6 = analogRead(E6);
    etatE7 = analogRead(E7);// potentiometre volume
    etatBusy = digitalRead(BUSY);    
    valVolume = map(analogRead(A7),0,1023,0,30); 
    //myDFPlayer.volume(valVolume);  

    if(etatE0 <=512 && etatBusy == 1)
      {
        myDFPlayer.setTimeOut(500);
        delay(40);
        myDFPlayer.volume(valVolume);
        myDFPlayer.play(3);        
      }
    if(etatE1 <=512 && etatBusy == 1)
      {
        myDFPlayer.setTimeOut(500);
        delay(40);
        myDFPlayer.volume(valVolume);
        myDFPlayer.play(1);        
      }
    if(etatE2 <=512 && etatBusy == 1)
      {
        myDFPlayer.setTimeOut(500);
        delay(40);
        myDFPlayer.volume(valVolume);
        myDFPlayer.play(12);        
      }
    if(etatE3 <=512 && etatBusy == 1)
      {
        myDFPlayer.setTimeOut(500);
        delay(40);
        myDFPlayer.volume(valVolume);
        myDFPlayer.play(4);        
      }
    if(etatE4 <=512 && etatBusy == 1)
      {
        myDFPlayer.setTimeOut(500);
        delay(40);
        myDFPlayer.volume(valVolume);
        myDFPlayer.play(5);       
      }
    if(etatE5 <=512 && etatBusy == 1)
      {
        myDFPlayer.setTimeOut(500);
        delay(40);
        myDFPlayer.volume(valVolume);
        myDFPlayer.play(11);        
      }
    if(etatE6 <=512 && etatBusy == 1)
      {
        myDFPlayer.setTimeOut(500);
        delay(40);
        myDFPlayer.volume(valVolume);
        myDFPlayer.play(13);        
      }
/******************************
  Commandes sons avec interval
*******************************/
    if((millis() - tempsPrecedentSon1) >= 90000 && (bitSon1 == 1))
      {
        tempsPrecedentSon1 = millis(); 
        tempsPrecedentSon2 = millis();       
        bitSon1 = 0;
        bitSon2 = 1; 
        compteur1 = compteur1 + 1;
        myDFPlayer.setTimeOut(500);
        delay(40);
        myDFPlayer.volume(valVolume);
        myDFPlayer.play(14);// angelus
      }
    if((millis() - tempsPrecedentSon2) >= 20000 && (bitSon2 == 1))
      {
        tempsPrecedentSon2 = millis();
        tempsPrecedentSon1 = millis();        
        bitSon1 = 1;
        bitSon2 = 0; 
        compteur2 = compteur2 + 1;
        myDFPlayer.setTimeOut(500);
        delay(40);
        myDFPlayer.volume(valVolume);
        myDFPlayer.play(8);// cloche
      }
/******************************
         Reset TF-16P
*******************************/
    if(etatBusy == 1)
      {
        tempsPrecedentReset = millis();
      }
    if(etatBusy == 0)
      {
        if((millis() - tempsPrecedentReset) >= 40000 )// en ms
          {
            tempsPrecedentReset = millis();
            myDFPlayer.reset();
            digitalWrite(LED13, HIGH);
            delay(1000);
            digitalWrite(LED13, LOW);
          }
      }
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

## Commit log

2024-06-28 C. Mercier 1er dépot le 28/06/2024
    [Kicad_Projet_Trains_Sons-B_Adhesive.gbr, Kicad_Projet_Trains_Sons-B_Courtyard.gbr, Kicad_Projet_Trains_Sons-B_Cu.gbr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]
2024-06-30 C. Mercier mise à jour dossier Gerber le 30/06/2024
    [Kicad_Projet_Trains_Sons-B_Adhesive.gbr, Kicad_Projet_Trains_Sons-B_Courtyard.gbr, Kicad_Projet_Trains_Sons-B_Cu.gbr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]
2024-11-01 C. Mercier mise à jour version V3 le 01/11/2025
    [Kicad_Projet_Trains_Sons-B_Adhesive.gbr, Kicad_Projet_Trains_Sons-B_Courtyard.gbr, Kicad_Projet_Trains_Sons-B_Cu.gbr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]
2024-11-01 C. Mercier Ajout fichier PCB le 01/11/2024
2024-11-01 C. Mercier Mise à jour version V3 le 01/11/2024
    [Kicad_Projet_Trains_Sons-B_Adhesive.gbr, Kicad_Projet_Trains_Sons-B_Courtyard.gbr, Kicad_Projet_Trains_Sons-B_Cu.gbr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]
